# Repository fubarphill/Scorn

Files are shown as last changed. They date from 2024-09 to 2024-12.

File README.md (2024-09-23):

# Scorn
A split ergo keyboard based on the Corne (crkbd) by Foostan

Increased pinky stagger, similar to Cantor/Piantor but with added splay on pinky columns.

Built using Ergogen.

## How to clone this repo

You must also include the footprints submodule from ceoloide. Please clone with --recursive mode:

##
    git clone --recursive git@github.com:fubarphill/Scorn.git

## Thanks and recognition

* [foostan](https://github.com/foostan/crkbd) - for the awesome Corne (Crkbd)
* [beekeeb](https://github.com/beekeeb/piantor) - for the Piantor, which made me realise I need a bigger stagger for my pinkies
* The [Ergogen](https://github.com/ergogen/ergogen) team - for the amazing tool
* [ceoloide](https://github.com/ceoloide) - for the extra ergogen footprints
* [FlatFootFox](https://flatfootfox.com/ergogen-part1-units-points/) - for the best Ergogen guide I've seen

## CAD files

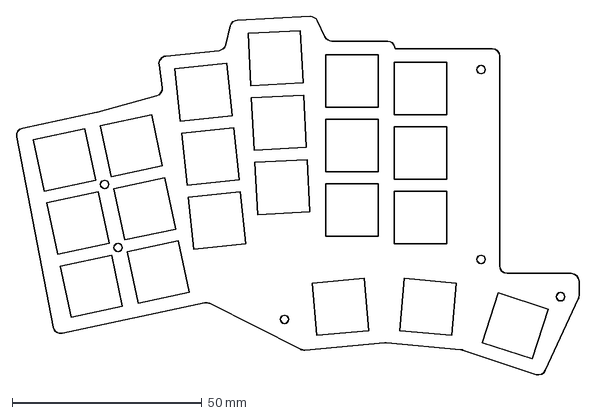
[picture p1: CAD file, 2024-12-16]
ergogen/output/outlines/switchplate.dxf
148.3 x 94.7 mm

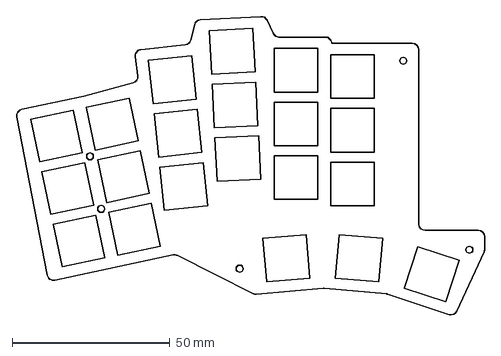
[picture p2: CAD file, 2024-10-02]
ergogen/v1_0/output/outlines/switchplate.dxf
148.3 x 94.7 mm

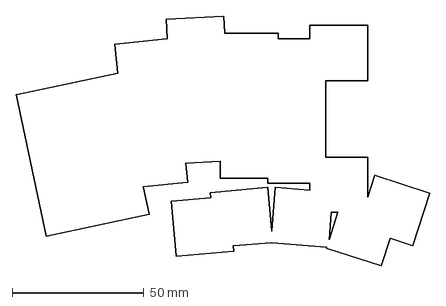
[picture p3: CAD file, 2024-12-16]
ergogen/output/outlines/raw.dxf
157.3 x 94.9 mm

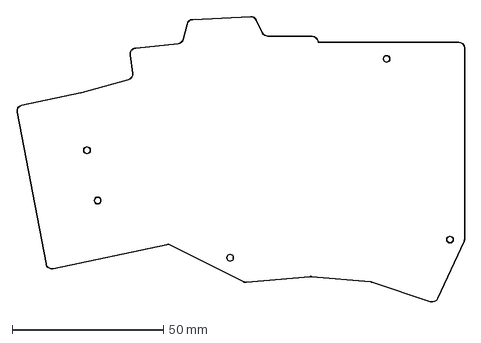
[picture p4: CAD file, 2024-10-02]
ergogen/v1_0/output/outlines/backplate.dxf
148.3 x 94.7 mm

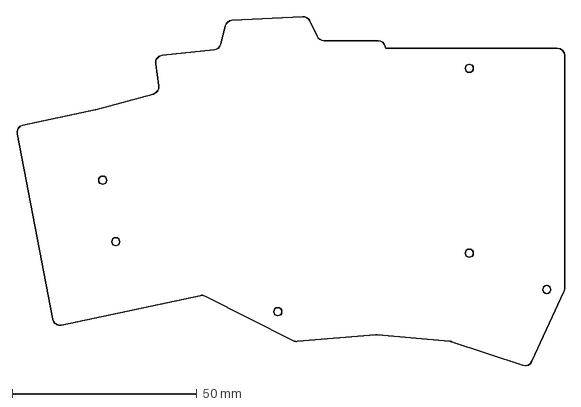
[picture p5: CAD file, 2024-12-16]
ergogen/output/outlines/backplate.dxf
148.3 x 94.7 mm

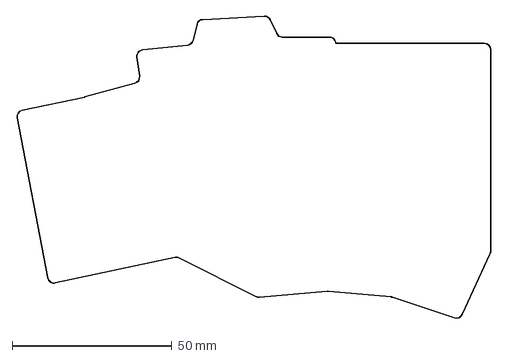
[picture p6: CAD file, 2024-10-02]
ergogen/v1_0/output/outlines/board.dxf
148.3 x 94.7 mm

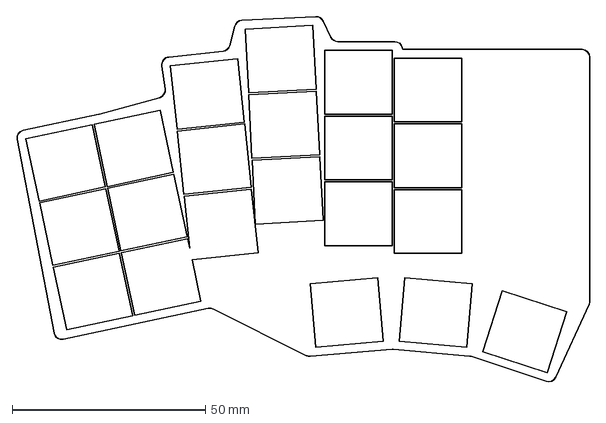
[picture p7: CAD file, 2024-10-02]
ergogen/output/outlines/combo.dxf
148.3 x 94.7 mm

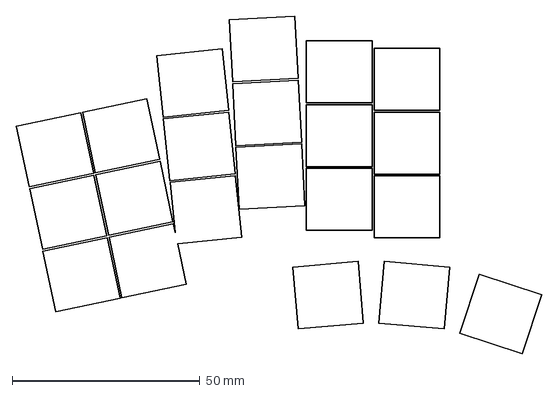
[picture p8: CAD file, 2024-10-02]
ergogen/v1_0/output/outlines/keys.dxf
139.9 x 89.7 mm

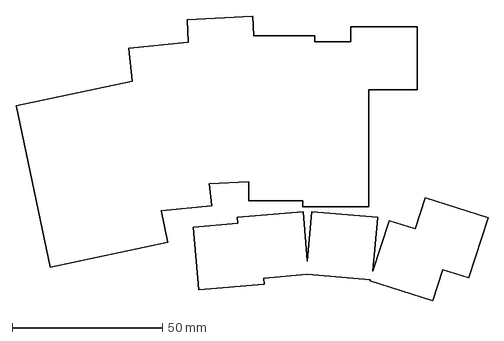
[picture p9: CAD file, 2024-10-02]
ergogen/v1_0/output/outlines/raw.dxf
157.3 x 94.9 mm

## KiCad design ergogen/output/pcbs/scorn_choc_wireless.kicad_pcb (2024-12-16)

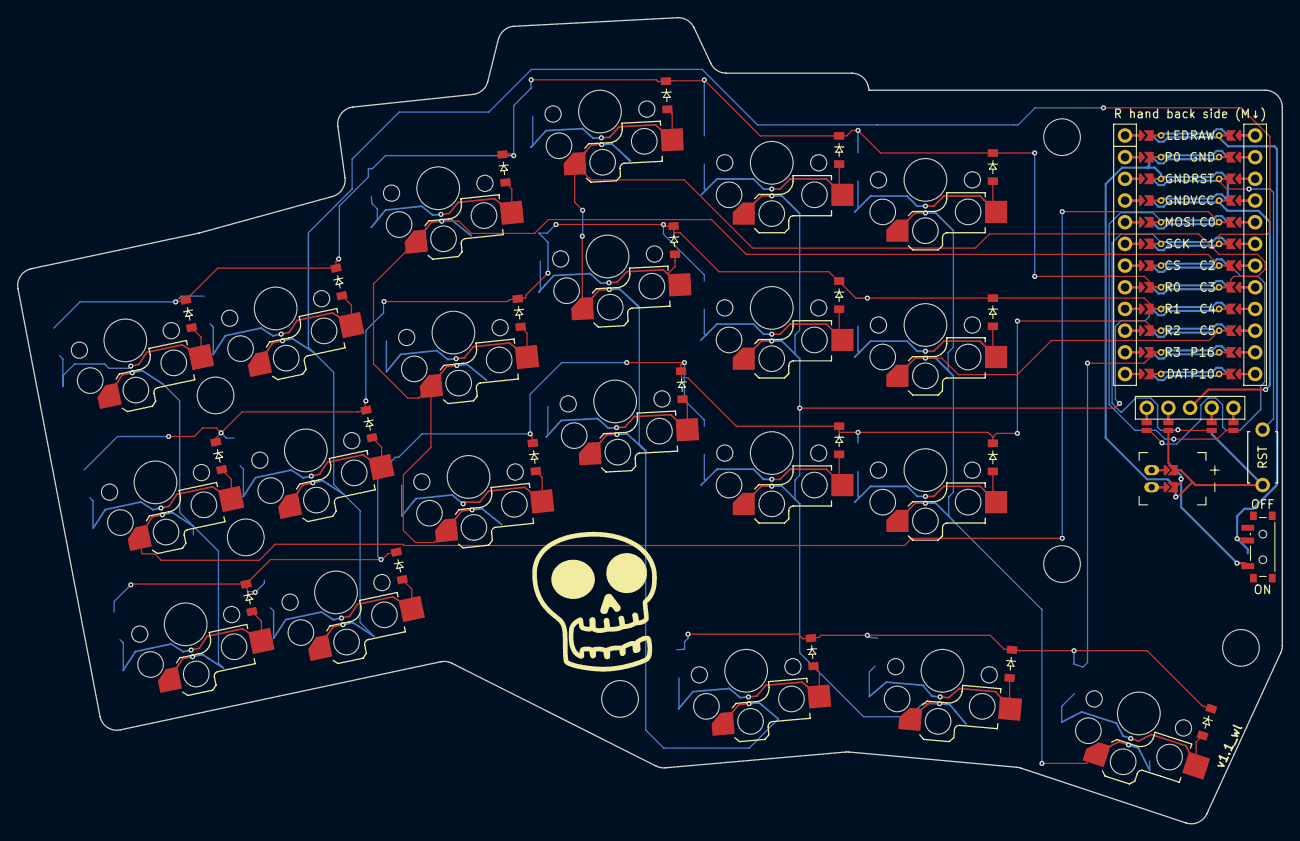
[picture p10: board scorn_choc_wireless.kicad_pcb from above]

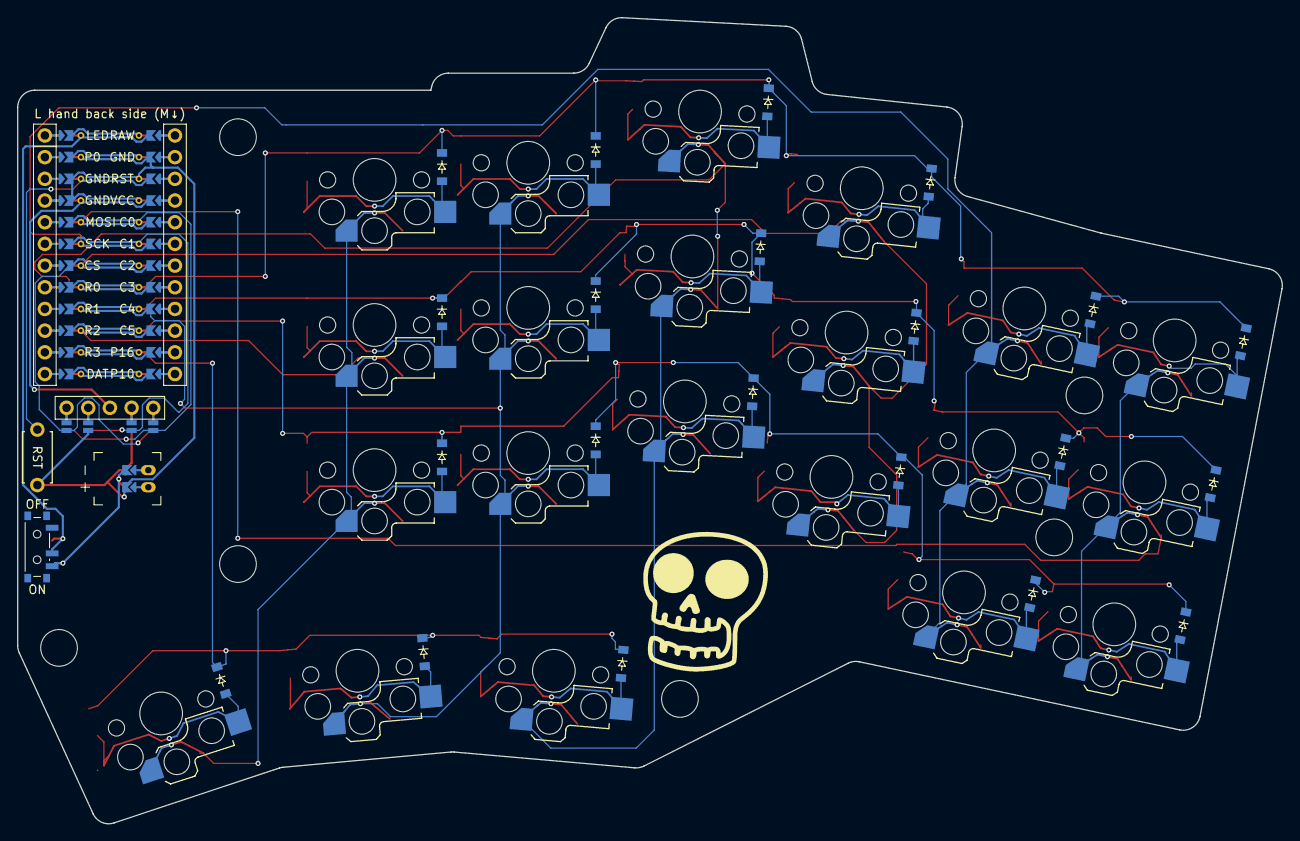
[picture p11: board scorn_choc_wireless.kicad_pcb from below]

Board: 2 copper layers, 148.1 x 94.4 mm, 76 parts (43 on the bottom side), 45 nets.

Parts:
BAT1: battery_connector_jst_ph_2
D1, D2, D3, D4, D5, D6, D7, D8, D9, D10, D11, D12, D13, D14, D15, D16, D17, D18, D19, D20, D21, D22, D23, D24, D25, D26, D27, D28, D29, D30, D31, D32, D33, D34, D35, D36, D37, D38, D39, D40, D41, D42: diode_tht_sod123
DISP1: display_nice_view
LOGO_B: LOGO; logo_sml
LOGO_F: LOGO; logo_sml_flp
MCU1: mcu_nice_nano
MH1, MH2, MH3, MH4, MH5, MH6: mounting_hole_npth
PWR1: power_switch_smd_side
RST1: reset_switch_tht_top
SW1, SW2, SW3, SW4, SW5, SW6, SW7, SW8, SW9, SW10, SW11, SW12, SW13, SW14, SW15, SW16, SW17, SW18, SW19, SW20, SW21: switch_choc_v1_v2

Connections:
BAT1_1: BAT1.11, BAT1.21, BAT1.31
BAT1_2: BAT1.12, BAT1.22, BAT1.32
BAT_P: BAT1.1, PWR1.1, PWR1.3
C0: MCU1.105, SW1.1, SW2.1, SW3.1
C1: MCU1.106, SW4.1, SW5.1, SW6.1
C2: MCU1.107, SW7.1, SW8.1, SW9.1
C3: MCU1.108, SW10.1, SW11.1, SW12.1, SW19.1
C4: MCU1.109, SW13.1, SW14.1, SW15.1, SW20.1
C5: MCU1.110, SW16.1, SW17.1, SW18.1, SW21.1
CS: DISP1.10, DISP1.20, MCU1.118
DISP1_1: DISP1.1, DISP1.14, DISP1.27
DISP1_2: DISP1.2, DISP1.15, DISP1.26
DISP1_4: DISP1.4, DISP1.16, DISP1.25
DISP1_5: DISP1.5, DISP1.17, DISP1.24
GND: BAT1.2, DISP1.11, DISP1.21, MCU1.102, MCU1.121, MCU1.122, RST1.2
MOSI: DISP1.13, DISP1.23, MCU1.120
R0: D3.1, D6.1, D9.1, D12.1, D15.1, D18.1, D24.1, D27.1, D30.1, D33.1, D36.1, D39.1, MCU1.117
R1: D2.1, D5.1, D8.1, D11.1, D14.1, D17.1, D23.1, D26.1, D29.1, D32.1, D35.1, D38.1, MCU1.116
R2: D1.1, D4.1, D7.1, D10.1, D13.1, D16.1, D22.1, D25.1, D28.1, D31.1, D34.1, D37.1, MCU1.115
R3: D19.1, D20.1, D21.1, D40.1, D41.1, D42.1, MCU1.114
RAW: MCU1.101, PWR1.2
RST: MCU1.103, RST1.1
SCK: DISP1.12, DISP1.22, MCU1.119
VCC: DISP1.3, MCU1.104
index_bottom: D13.2, D34.2, SW13.2
index_home: D14.2, D35.2, SW14.2
index_top: D15.2, D36.2, SW15.2
inner_bottom: D16.2, D37.2, SW16.2
inner_cluster: D19.2, D40.2, SW19.2
inner_home: D17.2, D38.2, SW17.2
inner_top: D18.2, D39.2, SW18.2
mid_cluster: D20.2, D41.2, SW20.2
middle_bottom: D10.2, D31.2, SW10.2
middle_home: D11.2, D32.2, SW11.2
middle_top: D12.2, D33.2, SW12.2
outer_bottom: D1.2, D22.2, SW1.2
outer_cluster: D21.2, D42.2, SW21.2
outer_home: D2.2, D23.2, SW2.2
outer_top: D3.2, D24.2, SW3.2
pinky_bottom: D4.2, D25.2, SW4.2
pinky_home: D5.2, D26.2, SW5.2
pinky_top: D6.2, D27.2, SW6.2
ring_bottom: D7.2, D28.2, SW7.2
ring_home: D8.2, D29.2, SW8.2
ring_top: D9.2, D30.2, SW9.2

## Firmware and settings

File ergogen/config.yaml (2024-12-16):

meta:
  engine: 4.1.0 # Min Ergogen version for KiCad 8 footprints
  name: Scorn
  author: fubarphill
  url: https://github.com/fubarphill/Scorn
units:
  $default_width: 'cx-0.5'
  $default_height: 'cy-0.5'
  # Proxy Spacing Variables
  kx: cx # 18mm Choc X spacing
  ky: cy # 17mm Choc Y spacing
  # Padding Variables
  px: kx + 4
  py: ky + 4
  # Additional variables for choc v1 switches
  ks: 19 # horizontal space between columns (default: 19)
  kp: 19 # vertical padding between keys (default: 19)
  kcow: 13.8 # key cutout hole width
  kcoh: 13.8 # key cutout hole height
  keycw: 17.5 # keycap width
  keych: 16.5 # keycap height
  led_pos_x: 0 # Led X position relative to the switch center
  led_pos_y: 4.7 # Led Y position relative to the switch center
  led_rotation: 0 # Led rotation
  vertical_diode_shift: 1.5 # How much to shift to avoid overlap
  horizontal_diode_shift: -0.5 kcow - 1
  diode_rotation: -180 # Diode rotation
  switch_rotation: 180 # Hotswap south, led north
  # Mounting measurements
  screw_radius: 1.1 # M2 screws
  screw_diameter: screw_radius * 2
  screw_head_radius: 2.05
  screw_head_diameter: screw_head_radius * 2
  spacer_radius: 2.15 # M2 standoffs
  spacer_diameter: spacer_radius * 2
points:
  zones:
    matrix:
      # Fix placement on KiCAD sheet.
      anchor:
        shift: [150, -150]
      key:
        padding: 1ky
        spread: 1kx
        tags:
          - key
          - matrix_key
      columns:
        outer:
          key:
            # splay: 8 #OG
            splay: 12
            column_net: C0
          rows:
            top.key:
              led_prev: LED_5
              led_next: LED_6
            home.key:
              led_prev: LED_6
              led_next: LED_7
            bottom.key:
              led_prev: LED_17
              led_next: LED_18
        pinky:
          key:
            column_net: C1
          rows:
            top.key:
              led_prev: LED_4
              led_next: LED_5
            home.key:
              led_prev: LED_7
              led_next: LED_8
            bottom.key:
              led_prev: LED_16
              led_next: LED_17
        ring:
          key:
            # stagger: 11.5 #OG
            # splay: -8 #OG
            stagger: 10
            splay: -6            
            column_net: C2
          rows:
            top.key:
              led_prev: LED_3
              led_next: LED_4
            home.key:
              led_prev: LED_8
              led_next: LED_9
            bottom.key:
              led_prev: LED_15
              led_next: LED_16
        middle:
          key:
            # stagger: 5 #OG
            stagger: 7
            splay: -3            
            column_net: C3
          rows:
            top.key:
              led_prev: LED_2
              led_next: LED_3
            home.key:
              led_prev: LED_9
              led_next: LED_10
            bottom.key:
              led_prev: LED_14
              led_next: LED_15
        index:
          key:
            # stagger: -5 #OG
            stagger: -7
            splay: -3
            column_net: C4
          rows:
            top.key:
              led_prev: LED_1
              led_next: LED_2
            home.key:
              led_prev: LED_10
              led_next: LED_11
            bottom.key:
              led_prev: LED_13
              led_next: LED_14
        inner:
          key:
            stagger: -2
            column_net: C5
          rows:
            top.key:
              led_prev: LED
              led_next: LED_1
            home.key:
              led_prev: LED_11
              led_next: LED_12
            bottom.key:
              led_prev: LED_12
              led_next: LED_13
      rows:
        bottom:
          row_net: R2
        home:
          row_net: R1
        top:
          row_net: R0
    thumbs:
      key:
        padding: 1ky
        spread: 1kx
        tags:
          - key
          - thumb_key
      anchor:
        ref: matrix_index_bottom
        shift: [2, -1.5ky]
      columns:
        inner:
          key:
            rotate: 5
            shift: [-5, 0]
            column_net: C3
          rows:
            cluster.key:
              led_prev: LED_18
              led_next: LED_19
        mid:
          key:
            rotate: -5
            column_net: C4
          rows:
            cluster.key:
              led_prev: LED_19
              led_next: LED_20
        outer:
          key:
            rotate: -18
            shift: [5, -5]
            column_net: C5
          rows:
            cluster.key:
              led_prev: LED_20
              led_next: LED_21
      rows:
        cluster:
          row_net: R3
    #Mounting helpers
    pcb_mounting_hole_topleft:
      key:
        tags:
          - helper
          - screw
      anchor:
          - ref: matrix_outer_top
            shift: [9, -8.5]
    pcb_mounting_hole_bottomleft:
      key:
        tags:
          - helper
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

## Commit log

2024-09-22 initial upload
    [board.dxf, combo.dxf, keys.dxf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]
2024-09-22 added footprints submodule
2024-09-29 pcb layout complete
    [combo.dxf, keys.dxf, raw.dxf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]
2024-10-02 stagger and splay rework
    [board.dxf, combo.dxf, keys.dxf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]
2024-10-02 adding files
    [backplate.dxf, scorn.kicad_pcb, switchplate.dxf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]
2024-10-02 cleaning up files
    [scorn-kicad.kicad_pcb, scorn-kicad.kicad_sch, scorn.kicad_pcb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]
2024-11-30 tidied up and collated v1 files
    [backplate.dxf, backplate.kicad_pcb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]
2024-12-16 update footprints submodule
2024-12-16 added v1.1
    [backplate.dxf, backplate.kicad_pcb, board.dxf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]
2024-12-16 updated v1.1
    [scorn_choc_wireless-B_Cu.gbr, scorn_choc_wireless-B_Mask.gbr, scorn_choc_wireless-B_Paste.gbp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]
